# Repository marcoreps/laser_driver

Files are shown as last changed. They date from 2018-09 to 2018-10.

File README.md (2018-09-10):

# laser_driver
Energy efficient constant current diode laser driver for CW operation

# Specs
* Input voltage range: 6.5V to 13.8V
* Output voltage range: 0.6V to 2.5V
* Max Output current: 40A to 50A
* Energy efficiency: Around 90% @ Iout > 10A
* Analog input voltage or >500 Hz PWM
* Operating ambient temperature: up to +70°C
* No overshoot
* Protected against reverse-polarity, short-circuit, over-voltage and over-temperature

# Schematic & description
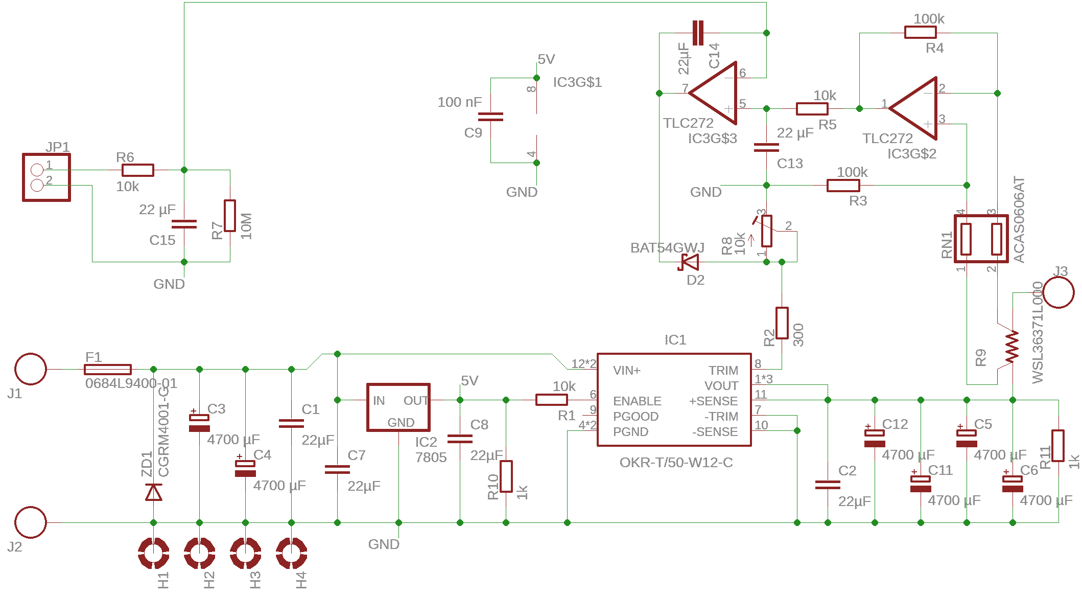
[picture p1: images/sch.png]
Schematic


An analog control voltage with 1V/10A or a 5V 500 Hz PWM signal with duty cycle 20%/10A is applied to JP1 and smoothed in a low-pass filter. IC3G$2 is a current shunt amplifier, generating 1V/10A. IC3G$2 compares the input control voltage and the actual output current voltage and drives the DC-DC converters trim pin accordingly. The circuit is an artifically slowed closed control loop because CW laser diodes often cannot take steep current slopes.

# Slope measurement
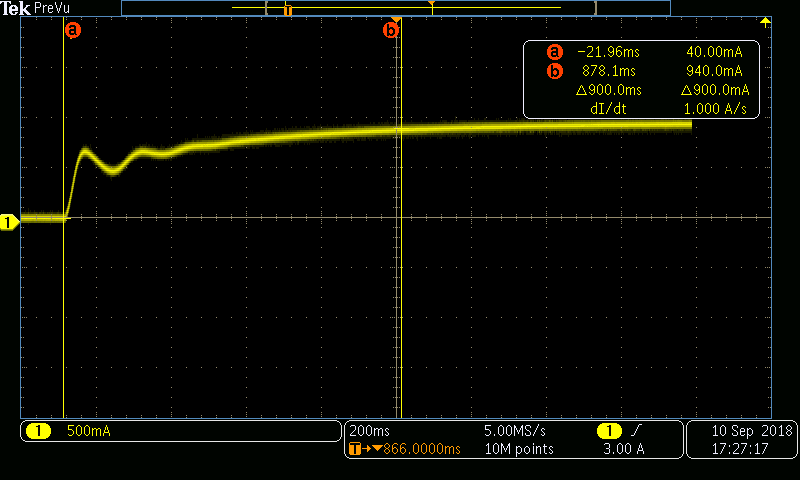
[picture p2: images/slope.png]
Slope


The displayed schematic is very slow, but guaranteed to never overshoot or oscillate. If desired for capacitors C13 and C14 lower values can be used to make the control loop respond faster. The displayed current waveform shows a start from 0A to 10A. It gets less wiggly when the baseline voltage is set closer to the laser diodes forward voltage, or when the current is not turned off all the way to 0A.

# Baseline Vout setting
Short or connect 0V to JP1, do not leave floating. Measure output voltage and adjust potentiometer R8 to set the baseline Vout to just under forward voltage of your laser diode. Don't make this adjustment while the laser diode is connected, there's a good chance of destroying it.

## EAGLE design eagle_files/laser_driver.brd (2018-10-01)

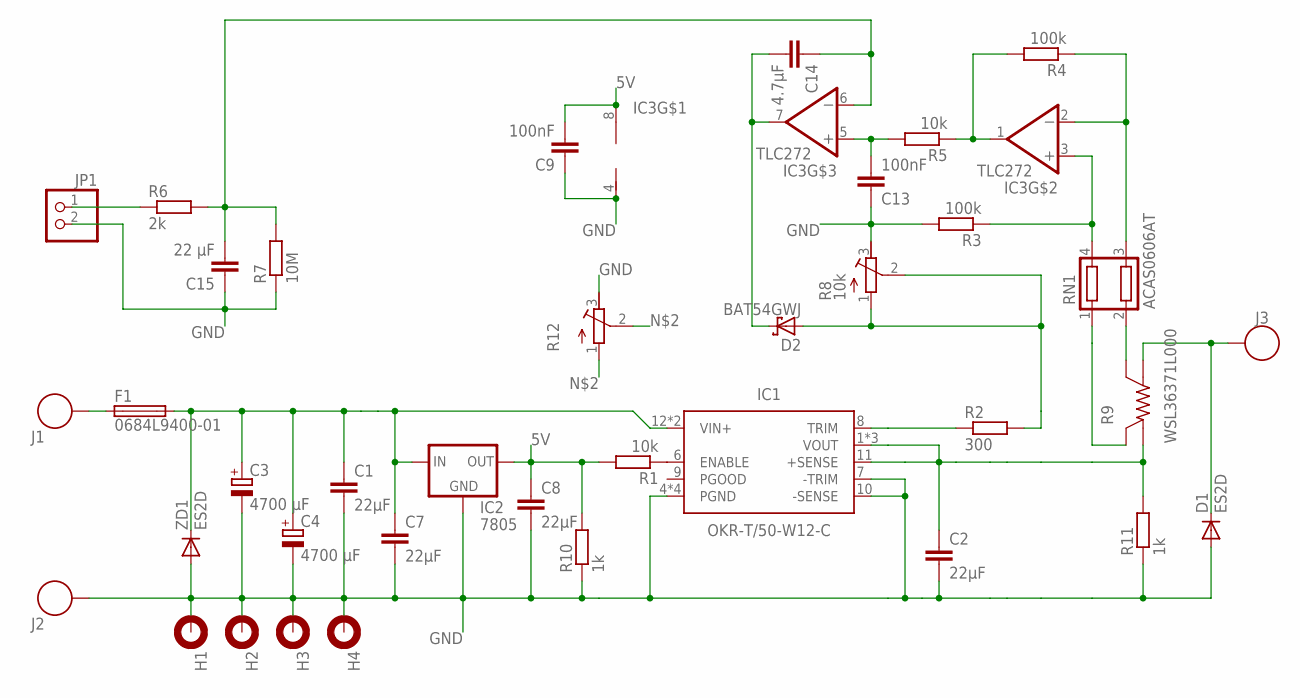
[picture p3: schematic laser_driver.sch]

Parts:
C1, C2, C7, C8: 22µF; C0805
C3, C4: 4700 µF; E7,5-16
C9, C13: 100nF; C0805
C14: 4.7µF; C0805
C15: 22 µF; C0805
D1: ES2D; SMB
D2: BAT54GWJ; SOD-123_MINI-SMA
F1: 0684L9400-01; 4818
H1, H2, H3, H4: MOUNT-PAD-ROUND3.0; 3,0-PAD
IC1: OKR-T/50-W12-C
IC2: 7805; TO252
IC3: TLC272; SO08
J1, J2, J3: 74650073R; FBGA90-6X15
JP1: PINHD-1X2; 1X02
R1, R5: 10k; R0805
R2: 300; R0805
R3, R4: 100k; R0805
R6: 2k; R0805
R7: 10M; R0805
R8: 10k; RTRIM64Y
R9: WSL36371L000; WSL3637
R10, R11: 1k; R0805
R12: R-TRIMM4G/J; RTRIM4G/J
RN1: ACAS0606AT; RESCAXS80P160X150X45-4
ZD1: ES2D; SMB

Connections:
5V: C8.1, C9.2, IC2.2 (OUT), IC3.8 (V+), R1.2, R10.2
CV: JP1.1, R6.1
ENABLE: IC1.6 (ENABLE), R1.1
GND: C1.2, C2.2, C3.-, C4.-, C7.2, C8.2, C9.1, C13.1, C15.1, D1.A, H1.B3,0, H2.B3,0, H3.B3,0, H4.B3,0, IC1.4 (PGND), IC1.5 (PGND), IC1.7 (-TRIM), IC1.10 (-SENSE), IC1.14 (PGND), IC1.15 (PGND), IC2.3 (GND), IC3.4 (V-), J2.P$1, J2.P$2, J2.P$3, J2.P$4, JP1.2, R3.2, R7.1, R8.3 (E), R10.1, R11.1, R12.3 (E), ZD1.A
unnamed: D1.C, J3.P$1, J3.P$2, J3.P$3, J3.P$4, R9.I1 (A)
unnamed: D2.A, R2.2, R8.1 (A), R8.2 (S), R12.1 (A), R12.2 (S)
unnamed: C2.1, IC1.1 (VOUT), IC1.2 (VOUT), IC1.3 (VOUT), IC1.11 (+SENSE), R9.I2 (B), R11.2
unnamed: F1.1, J1.P$1, J1.P$2, J1.P$3, J1.P$4
unnamed: R9.V1 (SA), RN1.2
unnamed: IC3.3 (+IN), R3.1, RN1.4
unnamed: R9.V2 (SB), RN1.1
unnamed: IC3.2 (-IN), R4.1, RN1.3
unnamed: IC3.1 (OUT), R4.2, R5.1
unnamed: C13.2, IC3.5 (+IN), R5.2
unnamed: C14.2, D2.C, IC3.7 (OUT)
unnamed: C14.1, C15.2, IC3.6 (-IN), R6.2, R7.2
TRIM: IC1.8 (TRIM), R2.1
VIN: C1.1, C3.+, C4.+, C7.1, F1.2, IC1.12 (VIN+), IC1.13 (VIN+), IC2.1 (IN), ZD1.C

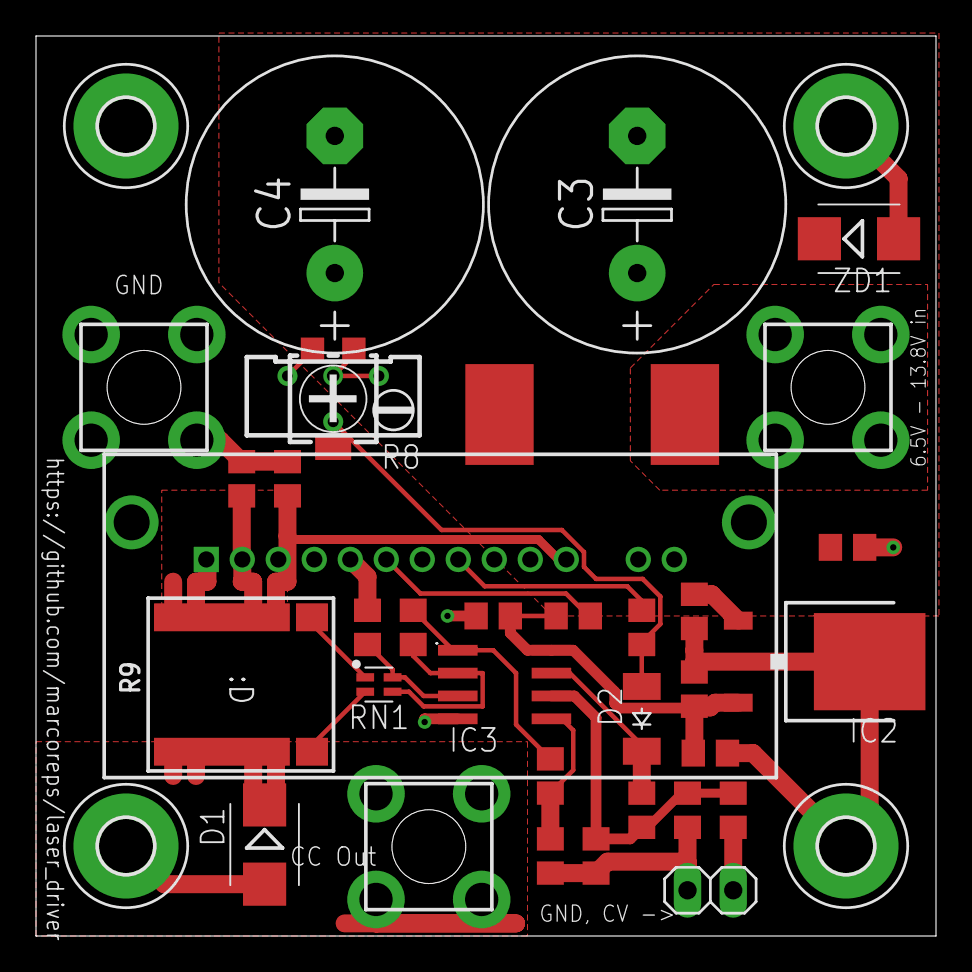
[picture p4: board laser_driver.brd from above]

Board: 2 copper layers, 50.0 x 50.0 mm, 38 parts (0 on the bottom side), 18 nets.

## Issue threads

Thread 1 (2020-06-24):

Help with part values

kcriqui, 2020-06-24:
What is the value of the resistors in RN1? Do those and R11 affect the gain of the shunt amplifier? I'm having a hard time understanding how that has an apparent gain of 20 (based on the 0.005 ohm shunt resistance)

daa5933, 2020-06-24:
RN1 is 1k

danriches, 2022-06-28:
I cannot find RN1 in stock anywhere or anything close to it. Does anyone have any suggestions as to how much I can derate this part? Such as using 2 0805's at 0.1% etc etc. I'll be redesigning the PCB anyway so now's the time to find parts which aren't unobtanium ;)

Cheers, Dan

danriches, 2022-07-07:
I see D1 on the board design but not on the schematics, what is the part number for this? I'm getting some boards made but want to be sure of this part first if at all possible. I'm guessing this is a transient suppression diode??

Thanks, Dan

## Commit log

2018-09-10 Added schematic to readme
2018-09-10 Cleaned up brd after cosmetic changes
    [laser_driver.brd]
2018-09-10 Elaboration on the wiggly current waveform
2018-09-23 Improved stability, removed useless caps
    [laser_driver.brd, laser_driver.sch]
2018-09-23 Improved silk screen
    [laser_driver.brd, laser_driver.sch]
2018-10-01 Minor changes in component placement after assembly
    [laser_driver.brd, laser_driver.sch]
